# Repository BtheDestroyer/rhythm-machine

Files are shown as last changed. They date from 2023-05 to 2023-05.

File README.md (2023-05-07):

# rhythm-machine

Arcade style rhythm game powered by the RP2040 microprocessor.

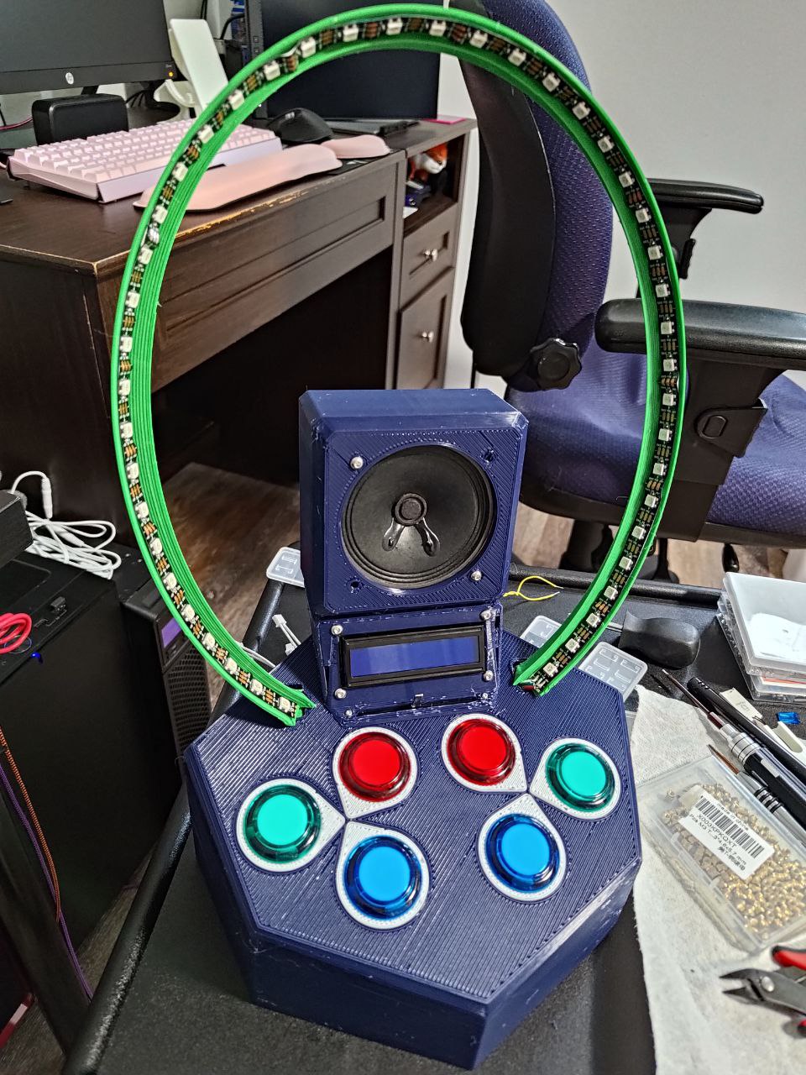
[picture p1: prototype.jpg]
Prototype


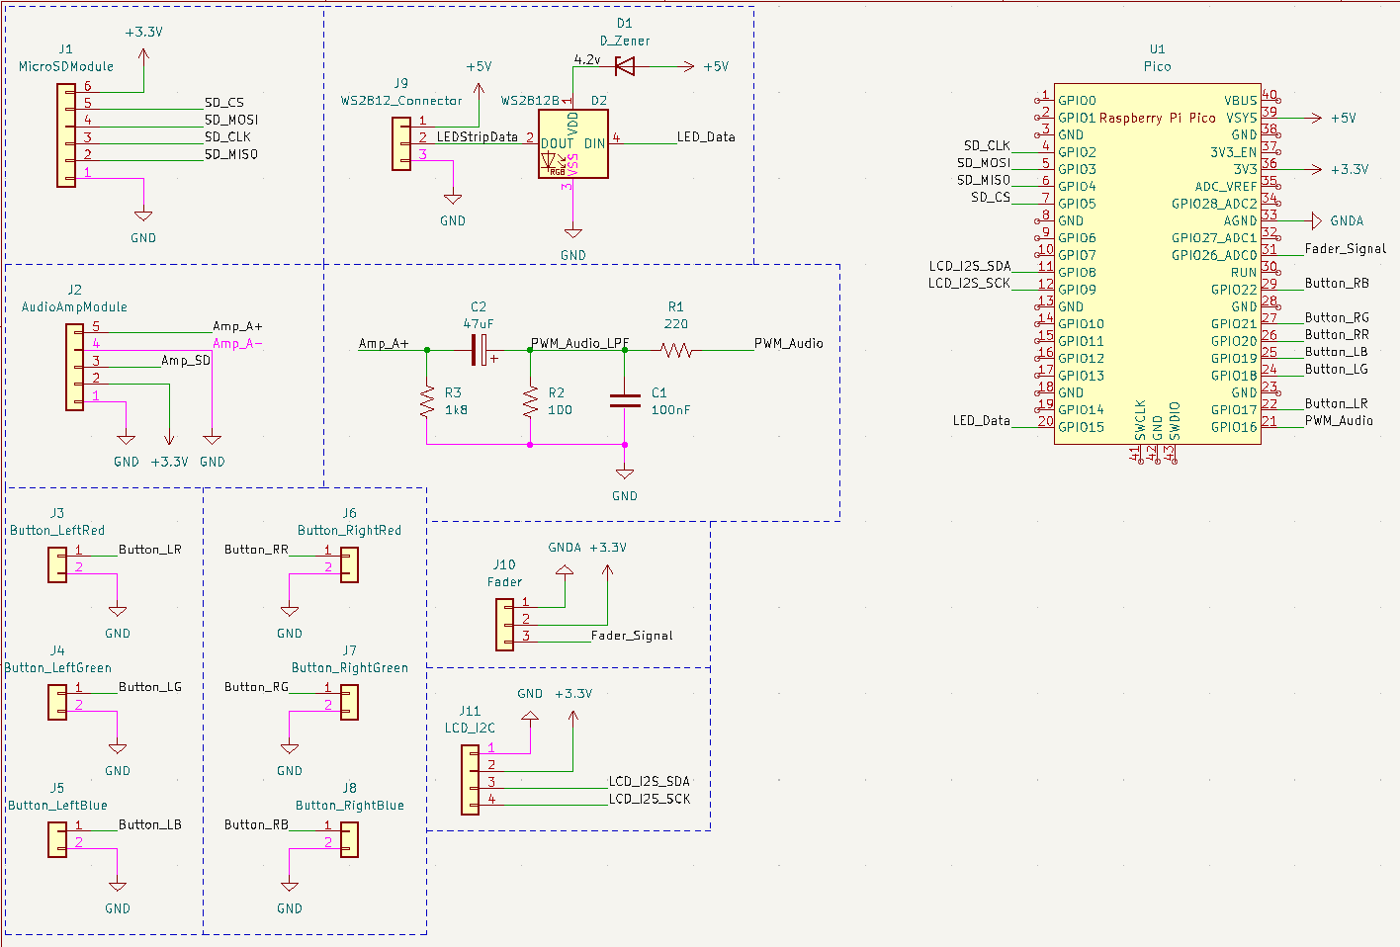
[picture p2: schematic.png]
Schematic


## To Do

- The Pico's power supply isn't sufficient for running the amp + speaker. A new one will have to be added to the PCB.
- The audio amp and SD card reader modules should be worked into the PCB directly rather than third-party items.
- Potentially ditch the Pico by integrating the RP2040 into the main PCB directly.

## Materials

Most links below are to Adafruit. None are affiliate links.

- 1x [Raspberry Pi Pico](https://www.adafruit.com/product/4864)
- 1x [3 inch, 3 watt speaker](https://www.adafruit.com/product/1314)
- 6x [Arcade buttons](https://www.adafruit.com/product/473)
  - Note: Get 2 of 3 different colors; Red + Green + Bluefloat
- 6x [Quick-connect JST cables](https://www.adafruit.com/product/1152)
  - Note: The link is to a pack of 10, so just one pack will be sufficient.
- 6x [2-Pin JST-XH connectors](https://www.digikey.com/en/products/detail/jst-sales-america-inc/B2B-XH-A-LF-SN/1651045)
- 1x [Micro SD card slot breakout board](https://www.adafruit.com/product/4682)
  - [Bulk alternative](https://www.amazon.com/gp/product/B0989SM146/)
- 1x [Micro SD card](https://www.amazon.com/SanDisk-COMINU024966-16GB-microSD-Card/dp/B004KSMXVM/)
  - Note: Avoid overpaying for these for projects. I'd recommend getting [a pack of 10 cards](https://www.amazon.com/dp/B0876H387X) between 8 and 32 GB.
- 1x [Class D audio amp](https://www.adafruit.com/product/2130)
- 1x [1602 LCD with 3.3v I2C adapter](https://www.amazon.com/gp/product/B08MPTND1V/)
  - Note: You can buy these pre-soldered, but you'll need to trim the pins down which may damage your wire cutters. I'd recommend getting some [cheap disposable ones](https://www.amazon.com/Hakko-CHP-170-Micro-Cutter/dp/B00FZPDG1K/) for this purpose.
- 45x [WS2812 addressable RGB LEDs](https://www.amazon.com/gp/product/B088BRY2SH/)
  - Note: Only 44 will be visible, but I'm using one as a makeshift logic level shifter.
- 1x Zener diode
  - [Various diode pack](https://www.amazon.com/EEEEE-Assortment-Rectifier-Recovery-Switching/dp/B08SBTS2KZ/)
  - This is only necessary if you're using one of the LEDs as a makeshift logic level shifter. If you have a dedicated logic level shifter, this isn't necessary
- 1x [75mm 10 kOhm Linear Slide Potentiometer](https://www.amazon.com/dp/B09NX39NWR?psc=1&ref=ppx_yo2ov_dt_b_product_details)
- 1x 47uF capacitor
  - [Electrolytic capacitor pack](https://www.amazon.com/BOJACK-Electrolytic-Capacitor-Assortment-0-1uF－1000uF/dp/B07PBQXQNQ/)
- 1x 10nF capacitor
  - [Ceramic capacitor pack](https://www.amazon.com/DYWISHKEY-Monolithic-Multilayer-Capacitors-0-1uF-100nF/dp/B07QGDGGZV/)
- 1x 100 Ohm resistor
- 1x 220 Ohm resistor
- 1x 1.8 kOhm resistor
  - [Resistor pack](https://www.amazon.com/BOJACK-Values-Resistor-Resistors-Assortment/dp/B08FD1XVL6/)
- 4x M3 6mm screws
- 4x M3 8mm screws
- 8x M3 nuts
- 2x M3 heat-set inserts
- 2x M2 8mm screws
  - For the above assembly hardware, I'd highly recommend just searching around for a kit. There are many options that offer different screw sizes, heads, bits, etc.

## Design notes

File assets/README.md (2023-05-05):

# rhythm-machine

## Assets

Playable songs are placed on the SD card in the following file structure:

- /
  - (Song Name)/
    - song.wav
    - song.note
  - (Song Name)/
    - song.wav
    - song.note

### 'song.wav' files

Contains the audio to be played during the song.

- Sampling rate: 22000Hz

- Format: 8-bit unsigned PCM

## 'song.note' files

Contains the information for when notes should be hit and how fast they travel.

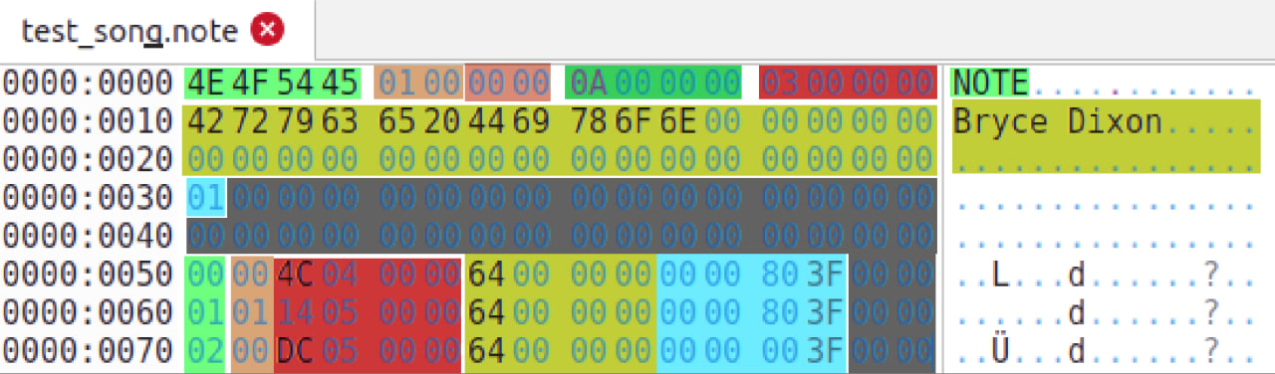
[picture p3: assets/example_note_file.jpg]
Example .note file


- Header Data
  - "NOTE" identifier
  - File major version
  - File minor version
  - Milliseconds per pixel
  - Notes in the song
  - Author name
  - Difficulty (1-10)
  - 31 bytes of padding
- Note data (duplicated for each note)
  - Color (red, green, or blue)
  - Direction (left or right)
  - Start time (ms)
  - Length (ms; 0 is no hold)
  - Speed (float; 1.0 is normal speed)
  - 2 bytes padding for the pretty alignment

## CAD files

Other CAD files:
models/Rhythm_Machine.blend

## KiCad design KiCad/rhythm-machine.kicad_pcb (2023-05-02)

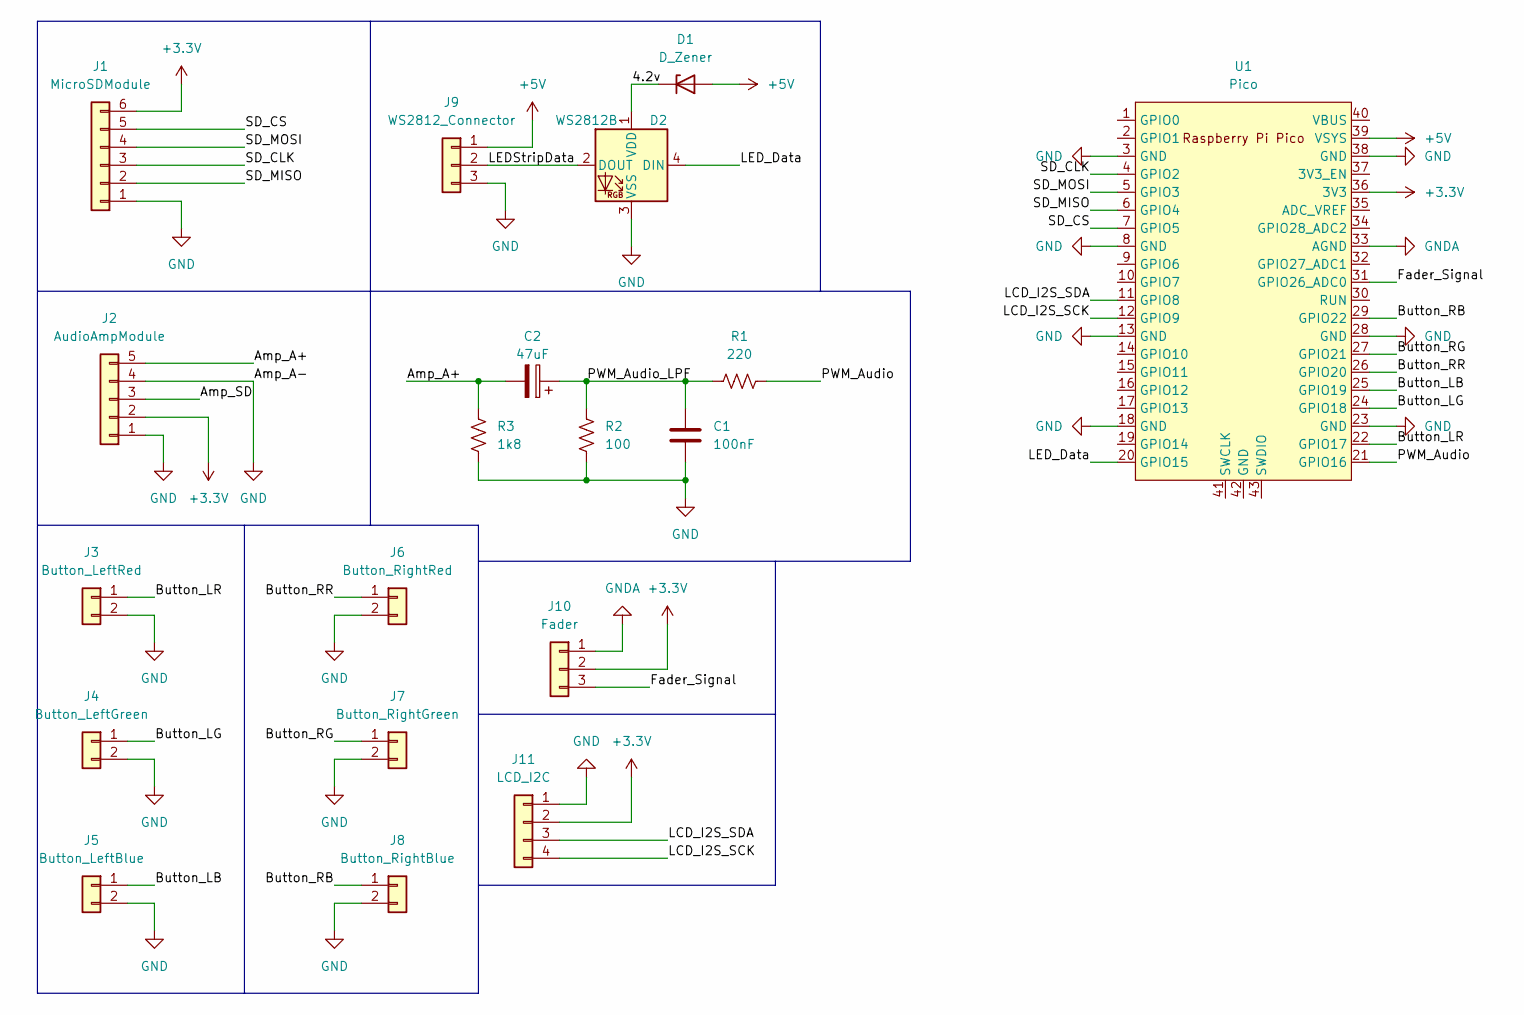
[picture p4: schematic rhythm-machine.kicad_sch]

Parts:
C1: 100nF; C_Disc_D4.3mm_W1.9mm_P5.00mm
C2: 47uF; CP_Radial_D4.0mm_P2.00mm
D1: D_Zener; D_T-1_P5.08mm_Horizontal
D2: WS2812B; WS2812B_Strip_Single
J1: MicroSDModule; PinHeader_1x06_P2.54mm_Vertical
J2: AudioAmpModule; PinHeader_1x05_P2.54mm_Vertical
J3: Button_LeftRed; JST_XH_B2B-XH-A_1x02_P2.50mm_Vertical
J4: Button_LeftGreen; JST_XH_B2B-XH-A_1x02_P2.50mm_Vertical
J5: Button_LeftBlue; JST_XH_B2B-XH-A_1x02_P2.50mm_Vertical
J6: Button_RightRed; JST_XH_B2B-XH-A_1x02_P2.50mm_Vertical
J7: Button_RightGreen; JST_XH_B2B-XH-A_1x02_P2.50mm_Vertical
J8: Button_RightBlue; JST_XH_B2B-XH-A_1x02_P2.50mm_Vertical
J9: WS2812_Connector; PinHeader_1x03_P2.54mm_Vertical
J10: Fader; PinHeader_1x03_P2.54mm_Vertical
J11: LCD_I2C; PinHeader_1x04_P2.54mm_Vertical
R1: 220; R_Axial_DIN0207_L6.3mm_D2.5mm_P7.62mm_Horizontal
R2: 100; R_Axial_DIN0207_L6.3mm_D2.5mm_P7.62mm_Horizontal
R3: 1k8; R_Axial_DIN0207_L6.3mm_D2.5mm_P7.62mm_Horizontal
U1: Pico; RPi_Pico_SMD_TH

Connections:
+3V3: J1.6, J2.2, J10.2, J11.2, U1.36 (3V3)
+5V: D1.2 (A), J9.1, U1.39 (VSYS)
/4.2v: D1.1 (K), D2.1 (VDD)
/Amp_A+: C2.2, J2.5, R3.2
/Amp_SD: J2.3
/Button_LB: J5.1, U1.25 (GPIO19)
/Button_LG: J4.1, U1.24 (GPIO18)
/Button_LR: J3.1, U1.22 (GPIO17)
/Button_RB: J8.1, U1.29 (GPIO22)
/Button_RG: J7.1, U1.27 (GPIO21)
/Button_RR: J6.1, U1.26 (GPIO20)
/Fader_Signal: J10.3, U1.31 (GPIO26_ADC0)
/LCD_I2S_SCK: J11.4, U1.12 (GPIO9)
/LCD_I2S_SDA: J11.3, U1.11 (GPIO8)
/LEDStripData: D2.2 (DOUT), J9.2
/LED_Data: D2.4 (DIN), U1.20 (GPIO15)
/PWM_Audio: R1.2, U1.21 (GPIO16)
/PWM_Audio_LPF: C1.2, C2.1, R1.1, R2.2
/SD_CLK: J1.3, U1.4 (GPIO2)
/SD_CS: J1.5, U1.7 (GPIO5)
/SD_MISO: J1.2, U1.6 (GPIO4)
/SD_MOSI: J1.4, U1.5 (GPIO3)
GND: C1.1, D2.3 (VSS), J1.1, J2.1, J2.4, J3.2, J4.2, J5.2, J6.2, J7.2, J8.2, J9.3, J11.1, R2.1, R3.1, U1.3 (GND), U1.8 (GND), U1.13 (GND), U1.18 (GND), U1.23 (GND), U1.28 (GND), U1.38 (GND)
GNDA: J10.1, U1.33 (AGND)

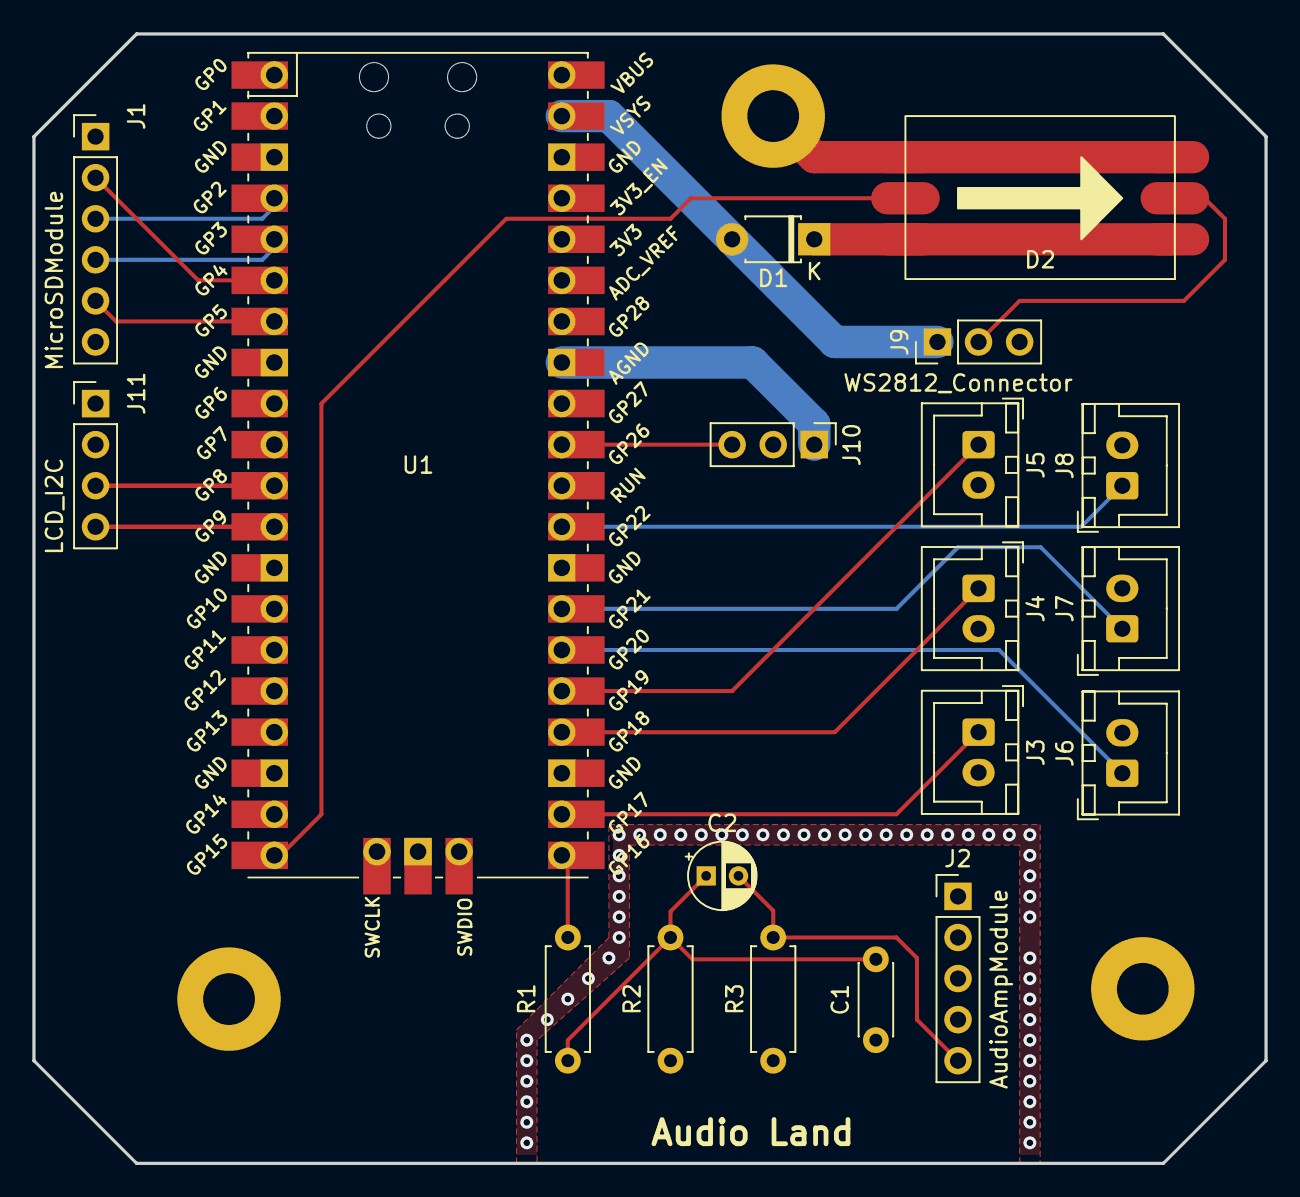
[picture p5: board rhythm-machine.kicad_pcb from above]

Board: 4 copper layers, 76.2 x 69.8 mm, 19 parts (0 on the bottom side), 23 nets.

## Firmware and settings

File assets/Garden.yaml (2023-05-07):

song:
  ms_per_pixel: 10
  lead_in_ms: 5000 # Delay added before all notes
  author: "Bryce Dixon"
  difficulty: 1

notes:
  - color: red
    direction: left
    start_ms: 142
    length_ms: 1200
  - color: green
    direction: right
    start_ms: 2450
    length_ms: 250
  - color: blue
    direction: right
    start_ms: 2960
    length_ms: 250
  - color: red
    direction: left
    start_ms: 3347
    length_ms: 1200
  - color: blue
    direction: right
    start_ms: 5000
    length_ms: 600
  - color: blue
    direction: right
    start_ms: 6219
    length_ms: 200
  - color: blue
    direction: right
    start_ms: 6720
    length_ms: 200
  - color: green
    direction: left
    start_ms: 7100
    length_ms: 1200

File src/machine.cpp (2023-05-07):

#include "machine.h"

namespace States
{
    SongList::SongList(Machine &machine)
    {
        machine.lcd.display("Loading songs...");
        for (const SDCard::FileEntry &entry : machine.sd.get_file_list("/"))
        {
            if (entry.type != SDCard::FileEntry::FileType::Directory)
            {
                continue;
            }
            std::optional<FILINFO> file_info{
                machine.sd.get_file_info((entry.name + "/song.wav").c_str())};
            if (!file_info.has_value())
            {
                continue;
            }
            songs.emplace_back(entry.name);
        }
    }

    void SongList::operator()(Machine &machine)
    {
        if (current_index != last_song_index)
        {
            if (songs.size() > 0)
            {
                machine.lcd.display(songs[current_index]);
            }
            else
            {
                machine.lcd.display("No songs on SD");
            }
            last_song_index = current_index;
        }
        if (songs.size() == 0)
        {
            return;
        }
        if (machine.buttons.right.blue.get_state() == Button::State::Pressed)
        {
            machine.current_song_path = songs[current_index];
            Audio::start_streaming_wave({(songs[current_index] + "/song.wav").c_str()});
            machine.switch_state<PlaySong>();
            return;
        }
        if (machine.buttons.right.red.get_state() == Button::State::Pressed)
        {
            current_index = (current_index + 1) % songs.size();
        }
        if (machine.buttons.left.red.get_state() == Button::State::Pressed)
        {
            if (current_index == 0)
            {
                current_index = songs.size() - 1;
            }
            else
            {
                --current_index;
            }
        }

        // Attract mode
        machine.leds.pattern_snakes(machine.get_current_tick());
        sleep_ms(12);
    }

    PlaySong::PlaySong(Machine &machine)
    {
        machine.leds.clear();
        machine.lcd.display(std::to_string(score));
        if (const auto loaded_song{ song_data::Song::load_from_note_file({(machine.current_song_path + "/song.note").c_str()}) })
        {
            song = loaded_song.value();
        }
        else
        {
            Audio::stop_streaming_wave();
            machine.switch_state<SongList>();
        }
    }

    void PlaySong::operator()(Machine &machine)
    {
        const std::uint64_t now_ms{ time_us_64() / 1000ull };
        if (now_ms != last_update_ms)
        {
            if (last_update_ms == ~0)
            {
                last_update_ms = now_ms; // Ensures the first loop has a delta time of 0
            }
            song.current_time_ms += now_ms - last_update_ms;
            last_update_ms = now_ms;

            const auto leds{ song.render_leds() };
            sleep_ms(4);
            machine.leds.show_pattern(leds);
        }
    }

    void PlaySong::increment_score(Machine &machine, std::uint32_t val)
    {
        score += val;
        machine.lcd.display(std::to_string(score));
    }
}

Machine::Machine()
{
    Audio::init();
    lcd.send_command(I2C_LCD::Command::DisplayControl, I2C_LCD::DisplayFlag::DisplayOn, I2C_LCD::DisplayFlag::CursorOn, I2C_LCD::DisplayFlag::BlinkOn);
    lcd.display("Hello, LCD");
    lcd.display("Reading SD...");
    if (!sd.init())
    {
        lcd.display("SD Card Error!");
        exit(1);
    }
    current_state = std::make_unique<States::SongList>(*this);
    //current_state = std::make_unique<States::PlaySong>(*this);
}

void Machine::update()
{
    buttons.left.red.update();
    buttons.left.green.update();
    buttons.left.blue.update();
    buttons.right.red.update();
    buttons.right.green.update();
    buttons.right.blue.update();
    Audio::stream_wave_to_inactive_buffer();

    if (current_state)
    {
        (*current_state)(*this);
        ++current_tick;
        if (next_state)
        {
            current_state = std::move(next_state);
        }
    }
}

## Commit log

2023-05-01 Added model
    [Rhythm_Machine.blend]
2023-05-01 Added prototype image
2023-05-01 Added material list to README
2023-05-01 Created PCB and schematic
    [rhythm-machine.kicad_pcb, rhythm-machine.kicad_sch]
2023-05-01 Updated pcb for production
    [rhythm-machine.kicad_pcb]
2023-05-01 Added image of schematic
2023-05-01 Added schematic to readme
2023-05-01 Removed autosaved files
    [rhythm-machine.kicad_sch]
2023-05-02 Connected Pico to GND net
    [rhythm-machine.kicad_pcb, rhythm-machine.kicad_sch]
2023-05-04 Added song data structs; started note->led rendering
